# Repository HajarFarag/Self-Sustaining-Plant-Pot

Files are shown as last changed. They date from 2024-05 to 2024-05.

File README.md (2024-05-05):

# Self Sustaining Plant Pot

## Table of Contents
- [Overview](#overview)
- [Demo](#demo)
- [Features](#features)
- [Technologies Used](#technologies-used)
- [Acknowledgements](#acknowledgements)

## Overview
The purpose of the project is to leave a plant unattended so it can find optimal sunlight and water the plants when required. This is done using an Arduino to control different components to achieve the goal of the project.
<br />


## Demo
*Note: Rubber tires were used for demo since PLA tracks did not have enough friction to move properly*
### Plant pot moving towards light
<br />


### Water Reservoir
<br />


<br />

## Features
- Sunlight Detection
- Watering System
- Movement Mechanism
- Obstacle Avoidance
- Battery Powered

## Technologies Used
- [Arduino](https://www.arduino.cc/ "Arduino's Homepage") - Microcontroller platform
- [C/C++](https://cplusplus.com/ "Arduino's Homepage") - Programming language
- [Ultimaker Cura](https://ultimaker.com/software/ultimaker-cura/ "Ultimaker Cura's Homepage") - 3D printing slicing software
- [AutoDesk Inventor](https://www.autodesk.com/products/inventor/features "Autodesk Inventor's Homepage") - 3D modeling and design software

## Acknowledgements
Thanks to: 
- [Nahuel Taibo](https://www.thingiverse.com/thing:2804287/ "Nahuel Taibo STL") for the Rover Track STL

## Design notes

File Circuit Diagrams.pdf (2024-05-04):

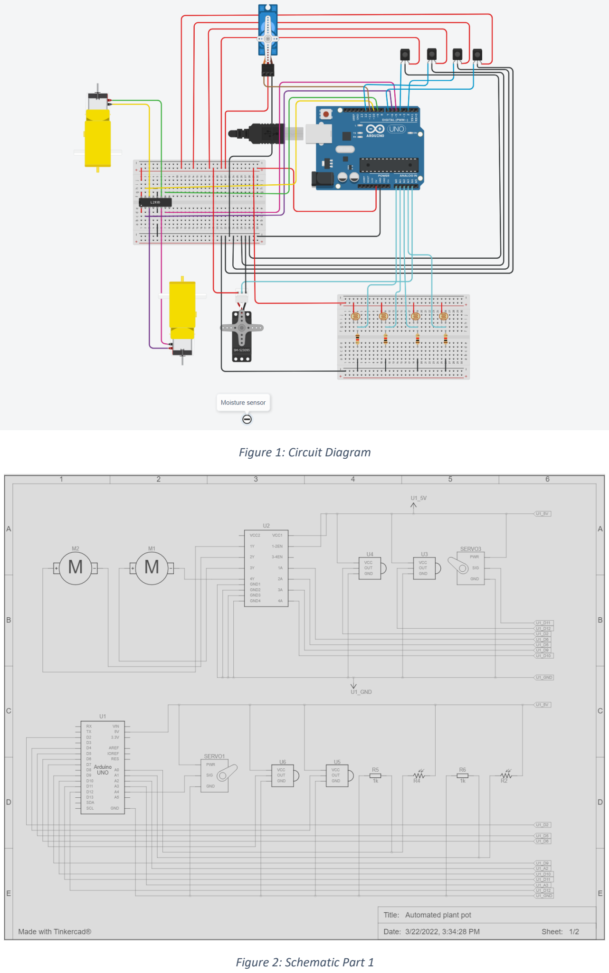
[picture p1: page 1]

Figure 1: Circuit Diagram

Figure 2: Schematic Part 1

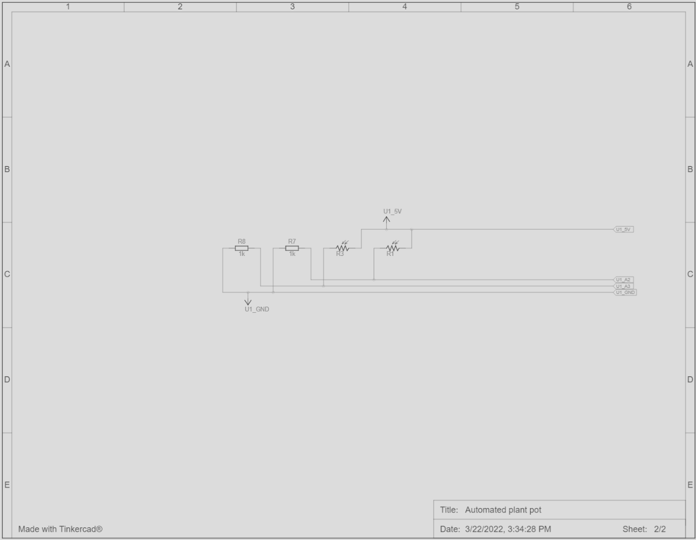
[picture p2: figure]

Figure 3: Schematic part 2

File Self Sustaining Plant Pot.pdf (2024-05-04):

Hajar Farag

Mohawk College of Applied Arts and Technology Department of Electrotechnology

## CENG-10024 – Capstone Project

Automated Plant Pot

Project submitted April 8th, 2022

Project Completed By:
Hajar Farag

2 | H a j a r F a r a g

## Abstract

This report is about the capstone project that was assigned as the final project of the program. The purpose of the project is to leave a plant unattended so it can find optimal sunlight and water the plants when required. This is done using an Arduino to control different components to achieve the goal of the project.

## Table of Contents

Abstract | 2
Table of Figures | 2

### 1. Introduction | 4 2. Theory of Operation and Background Information | 4 3. Project Description | 8 4. Bill of Materials | 8 5. Project Construction | 8 5.1. Materials needed | 8 5.2. Tools needed | 8

5.3. 3D Prints needed | 9

6. Testing and Observations | 17 6.1. Testing | 17 6.2. Observations | 17 7. Project Outcome | 18 8. Timeline and Milestones | 19 9. Conclusion | 20 10. Future Work/Recommendation | 20 11. References | 21 12. Appendix | 22 12.1 Appendix A – Code used for Automated Plant pot | 22 12.2 Appendix B – Schematic Diagram for Automated Plant Pot | 28 12.3 Appendix C – Datasheet Screenshots | 30

## Table of Figures

Figure 1: Theoretical circuitry connections | 5
Figure 2: Flow chart logic | 6
Figure 3: Sumo Bot Schematic | 7
Figure 4: Auto Watering System | 7
Figure 5: Lower section of the housing in AutoDesk Inventor | 10
Figure 6: Ultimaker Cura Orientation for Lower housing | 10

3 | H a j a r F a r a g

Figure 8: Circuitry connections (Note A Micro server was used in the diagram since a moisture sensor

4 | H a j a r F a r a g

## 1. Introduction

There are artificial lamps that could supply artificial sunlight to indoor plants, however artificial lamps do not supply the same wavelength of light as sunlight. Which would lead the plants to miss out on the full benefits of the sunlight. Nowadays everything is automated which is what gave me the idea to create an automated sunlight detecting pot. While working at Evertz, I learned how to create scripts to do automated testing. This opened my eyes to how everything around us is slowly being changed into an automated system. From smart fridges to smart cars, everything is being automated. My mother always moves her plants towards sunlight three times a day for the plants to get the optimal amount of sunlight. This system will allow the pots to move towards sunlight and waters the plants without any supervision.

## 2. Theory of Operation and Background Information

The automated plant pot will supply a sufficient amount of sunlight as well as water the plants when needed. An Arduino will be used to control the motors and collect inputs from the sensors. If the Arduino receives a value of less than 50% on the Moisture sensor, it will actuate the servo motor and move the water gate allowing water to flow to the soil. The LDR sensors send constant data to the Arduino and the Arduino checks the data in a loop. If one LDR sensor has a greater value compared to all the LDR sensors, the Arduino sends a PWM to the H-bridge which then controls the DC motors speed and direction of movement. Once the Pot starts moving, the Arduino code checks the IR sensor every loop to see if there is an object in front of the sensor. If the value on either IR sensor is above 250, the motor would move the opposite direction of the where the object is.
One of the technical issues encountered were the rover tracks. The tracks did not have enough traction since it was made from PLA filament which resulted in the pot not being able to move. One of the possible solutions would be to replace the tracks with a rubber belt which would have enough traction to move the pot. This solution was not used since the right track size was not available online.
Another solution would be replacing the tracks with rubber wheels which would make the whole pot more stable and would have enough traction to move the pot. This solution was used for demonstration since it was the optimal solution, however rubber tracks were not found tires online, so tires from Remote-Controlled Car were used instead.
Similar projects to my project would be a sumo bot: the sumo bots use motors and IR sensor which are some of the materials that the automated plant pot uses. Another similar project would be AutoPot Watering system. This is a similar application to my automated plant pot due to the watering system which waters the plants on its own. The contributions to the project would be 3D designing the housing, pot, and water reservoir, adding a moisture sensor which would detect the moisture of the plants soil, watering the plant using a water reservoir, and moving the pot towards sunlight.

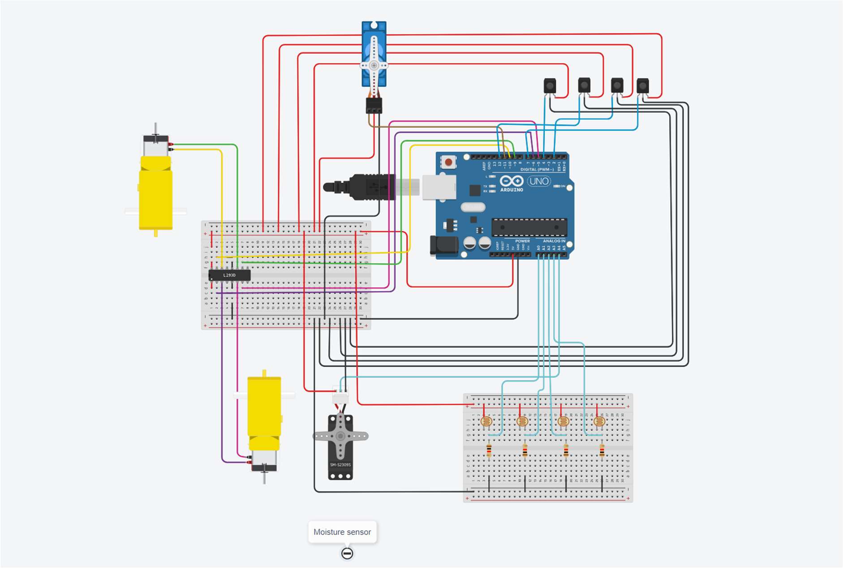
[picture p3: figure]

5 | H a j a r F a r a g

Figure 1: Theoretical circuitry connections

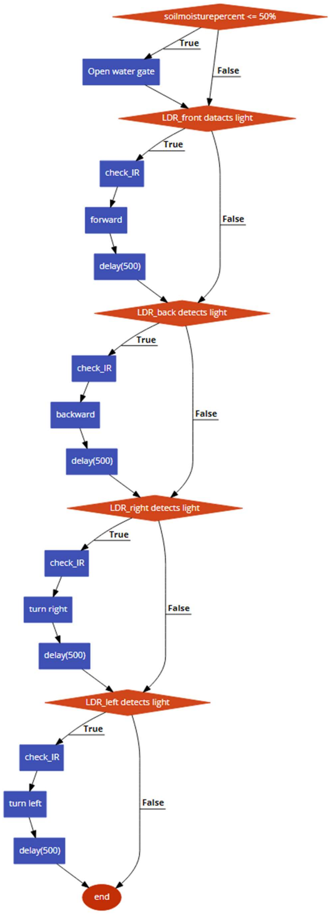
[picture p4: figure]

6 | H a j a r F a r a g

Figure 2: Flow chart logic

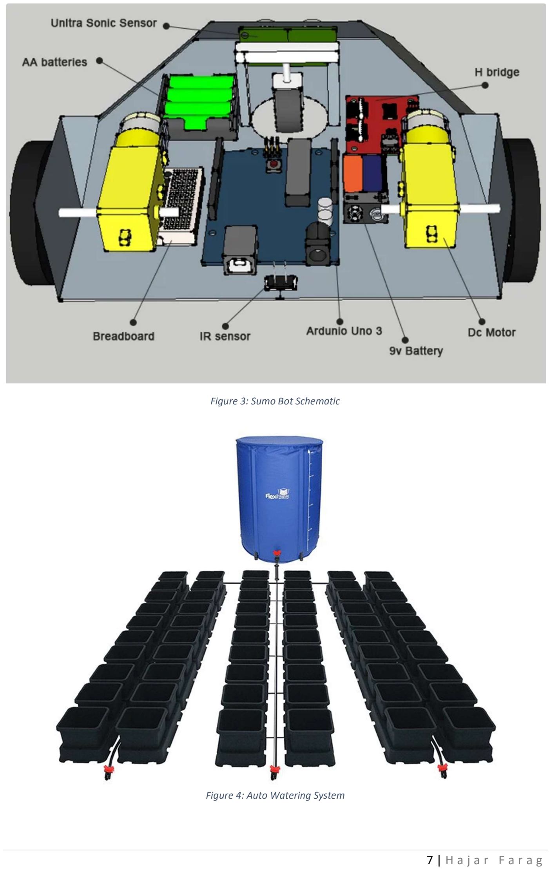
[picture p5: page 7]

7 | H a j a r F a r a g

Figure 3: Sumo Bot Schematic

Figure 4: Auto Watering System

8 | H a j a r F a r a g

## 3. Project Description

The Automated Plant Pot follows sunlight and waters the plants when the moisture of the soil decreases below a certain percentage. An Arduino based controller will be mounted on the pot which will control where the pot will move. Motors will be placed on the bottom of the pot to move the pot towards sunlight. LDR sensors will be used to detect the sunlight. IR sensors will be used to make sure the pot will not bump into anything while moving. A pulley system will be used to make the pot move to the optimal point where the sunlight is. A soil moisture sensor will be used to measure the moisture of the soil. If the moisture is low, the servo motor will rotate allowing the water to flow to the soil.

## 4. Bill of Materials

Budget Item | Quantity | Cost
DC Motor | 2 | 15
Servo Motor | 1 | 10
LDR | 4 | 10
Breadboard | 1 | 3
Capacitive Soil Moisture sensor | 1 | 10
M3x10mm Screw | 15 | 13
9V Batteries | 1 | 5
Battery House | 1 | 4.5
PLA Filament | 1 | 30
H-Bridge | 1 | 15
Total | | $115.5

## 5. Project Construction

### 5.1. Materials needed

- 1.75mm PLA Filament
- Lead Free Solder
- 1x Arduino Mega 2560
- 1x SG90 Micro Servo Motor
- 1x L298N Motor Drive
- 1x Capacitive Soil Moisture Sensor
- 1x Breadboard
- 1x Battery House (4 AA Battery Holder)
- 1x 9V Batteries
- 2x DC motors
- 4x AA Batteries
- 4x IR sensor
- 4x LDR sensors
- 4x 1k ohm resistors
- 12x M3x10mm screw
- 10x wires

### 5.2. Tools needed

- FDM Printer

9 | H a j a r F a r a g
- Screwdriver
- Soldering Iron

### 5.3. 3D Prints needed

Note: The STL files that are in a blue font are an external STL files created by a 3rd party.
- 1x Lower_Housing.stl
- 1x Upper_Housing.stl
- 1x Pot.stl
- 1x Water_Reservoir.stl
- 1x Water_Gate.stl
- 2x MotorMount_Enclosire.stl
- 2x MotorMount.stl
- 2x Wheels_Enclosure_A.stl
- 2x Wheels_Enclosure_B.stl
- 2x Wheel_Drive_A.stl
- 2x Wheel_Drive_B.stl
- 4x Wheel_Slave.stl
- 4x Wheel_Enclosure_Connector.stl
- 44x Track.stl
Procedure
The following procedure was used to create the project.
1. The STL Files listed above were printed individually.
2. A wire was attached to each pin of the DC motor using the soldering iron and solder.

### 3. The DC motor was placed in the Motor Mount Enclosure and ensured the wires were

coming out of the 10 mm opening.
4. The motor was then placed in the Motor Mount on top to secure the motor.
5. 2 wheels enclosure connectors were placed on the motor mount and motor mount enclosure to hold the parts together.
6. Wheel Drive A and Wheel Drive B were attached to the DC motor shaft by sliding them into the shaft.

### 7. A wheel slave was then placed on the motor mount enclosure and secured with a

M3x10mm screw then another wheel slave was placed on the other side of the motor mount and secured with M3x10mm screw.

### 8. Wheels Enclosure B was then aligned with the opening on the motor mount enclosure and

2 M3x10mm screws were used to attach the parts together.

### 9. The 22 Tracks were attached to each other using the 1.75 mm PLA filament and then

melting the tips to make sure the PLA does not slide off.

### 10. The tracks were then slid onto the wheel drive and wheel slave 11. Wheel Enclosure A was then placed on the Wheel Enclosure connector facing the Motor

Mount and 4 M3x10mm screws were used to attach the parts together.
12. Steps 2-11 were done again using the second DC motor.

### 13. AutoDesk Inventor was then used to design the bottom section of the housing with the

consideration of where the components will be placed.

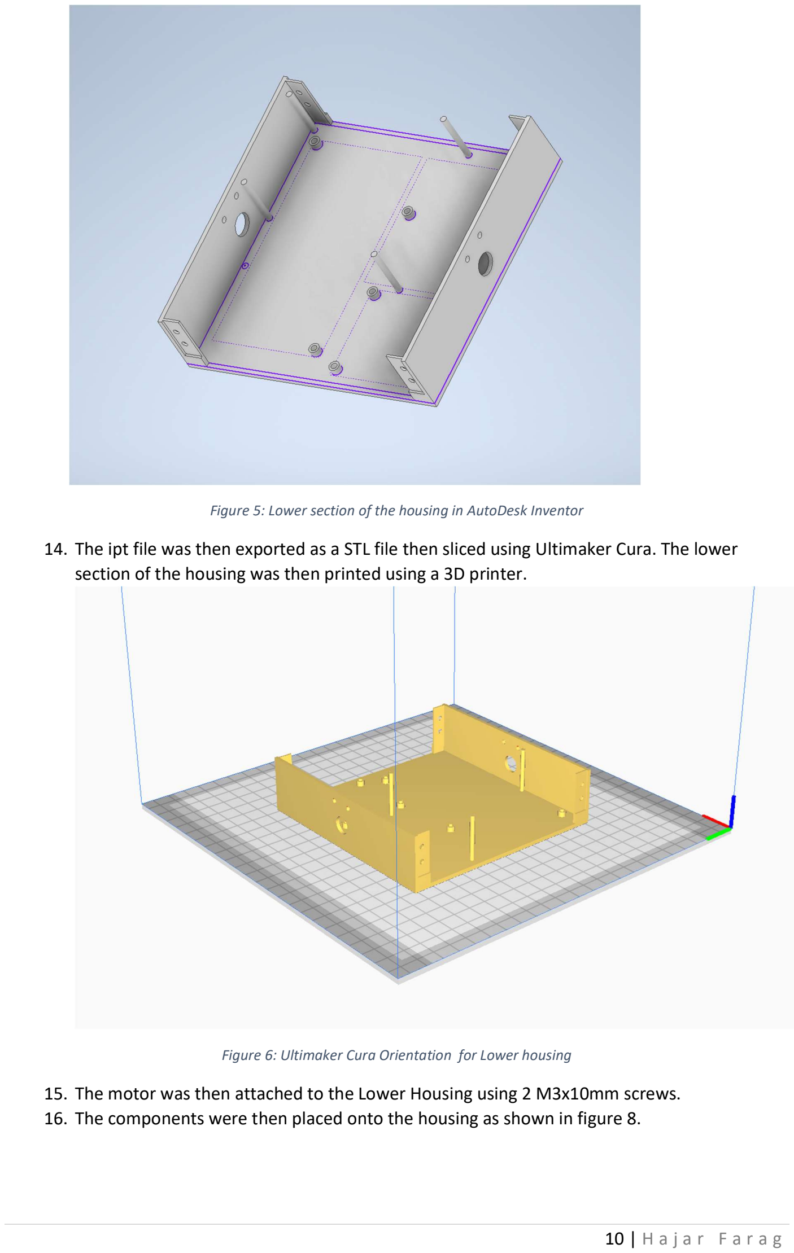
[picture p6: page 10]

10 | H a j a r F a r a g

Figure 5: Lower section of the housing in AutoDesk Inventor
14. The ipt file was then exported as a STL file then sliced using Ultimaker Cura. The lower section of the housing was then printed using a 3D printer.

Figure 6: Ultimaker Cura Orientation for Lower housing
15. The motor was then attached to the Lower Housing using 2 M3x10mm screws.
16. The components were then placed onto the housing as shown in figure 8.

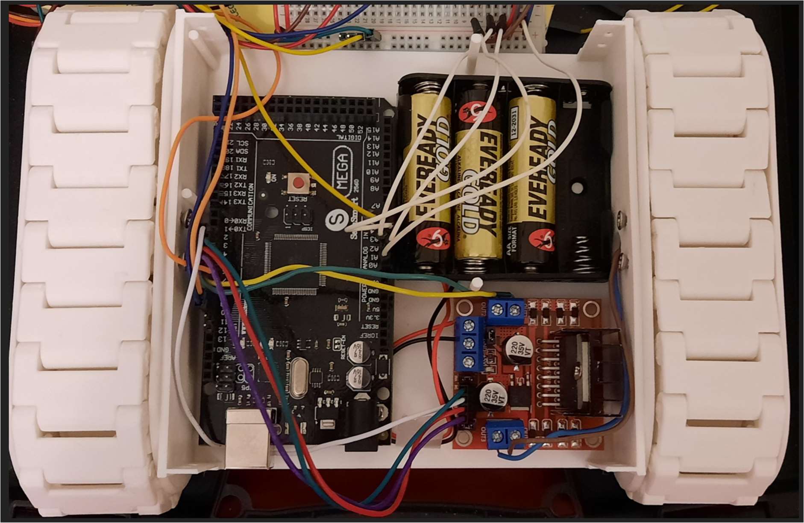
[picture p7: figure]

11 | H a j a r F a r a g

Figure 7: Components placement onto the housing
17. The circuitry was then connected using the components listed in Table 1 and was connected as shown in figure 3.

Table 1: Components needed for circuitry
2x DC Motor | 1x Servo Motor
1x H-Bridge | 1x Arduino Mega 2560
1x Moisture Sensor | 4x IR Sensor
4x 1k ohm resistor | 4x LDR Sensors

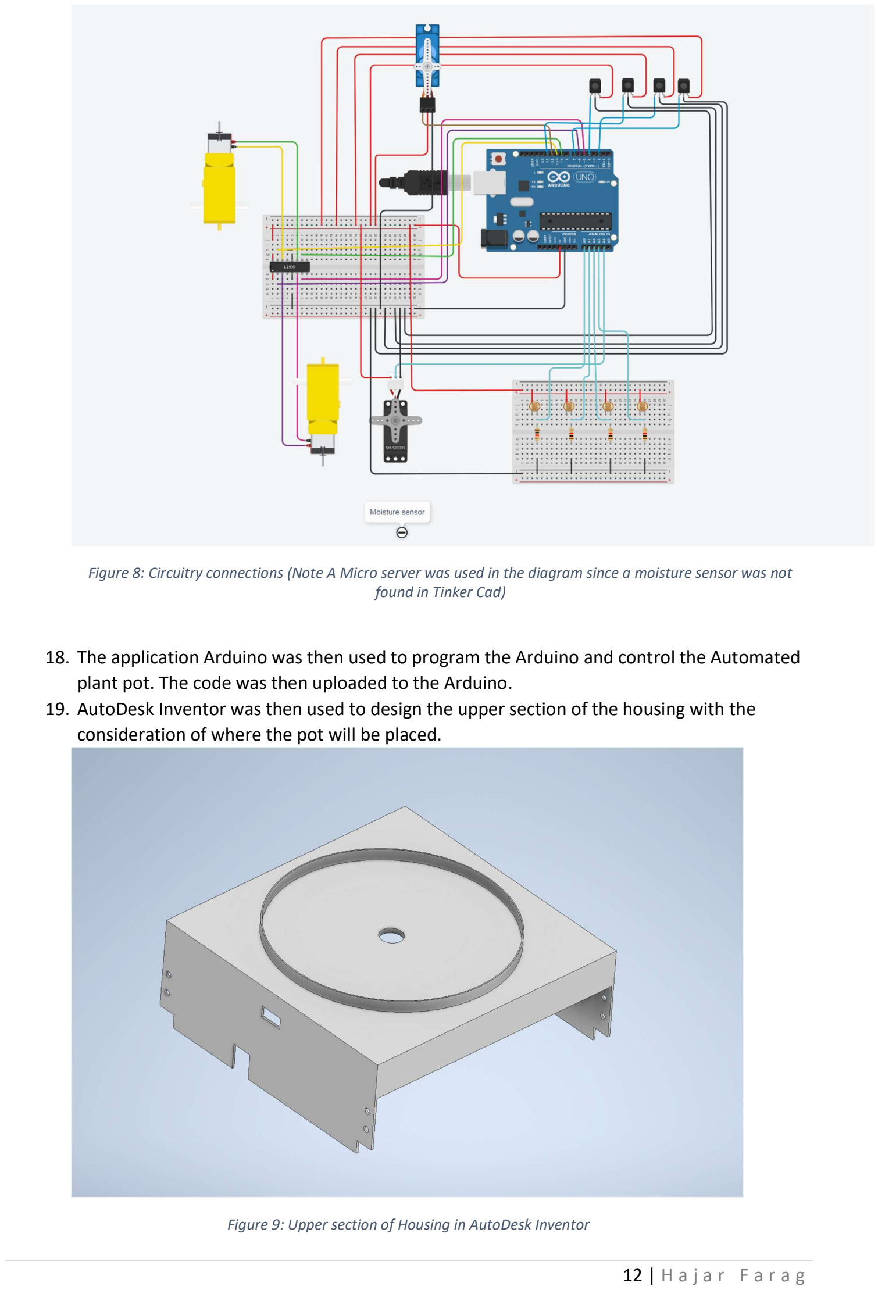
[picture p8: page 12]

12 | H a j a r F a r a g

Figure 8: Circuitry connections (Note A Micro server was used in the diagram since a moisture sensor was not found in Tinker Cad)

18. The application Arduino was then used to program the Arduino and control the Automated plant pot. The code was then uploaded to the Arduino.

### 19. AutoDesk Inventor was then used to design the upper section of the housing with the

consideration of where the pot will be placed.

Figure 9: Upper section of Housing in AutoDesk Inventor

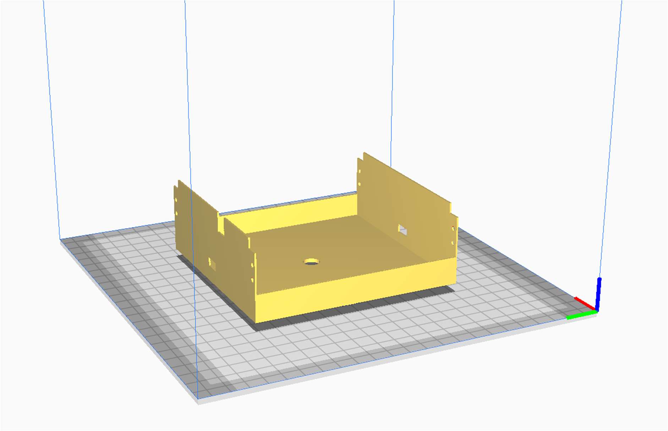
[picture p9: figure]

13 | H a j a r F a r a g
20. The ipt file was then exported as a STL file then sliced using Ultimaker Cura. The Upper section of the housing was then printed using a 3D printer.

Figure 10: Ultimaker Cura Orientation for Upper housing
21. The IR sensors, Servo Motor, and Moisture sensor were then put through the rectangular openings on the side of the upper housing.

### 22. The LDR wires were then slid into the opening ontop of the housing then 8 M3x10mm

screws were used to secure the Upper Housing to the Lower Housing.

### 23. AutoDesk Inventor was then used to design the pot with the consideration of where the

Water reservoir will be placed.

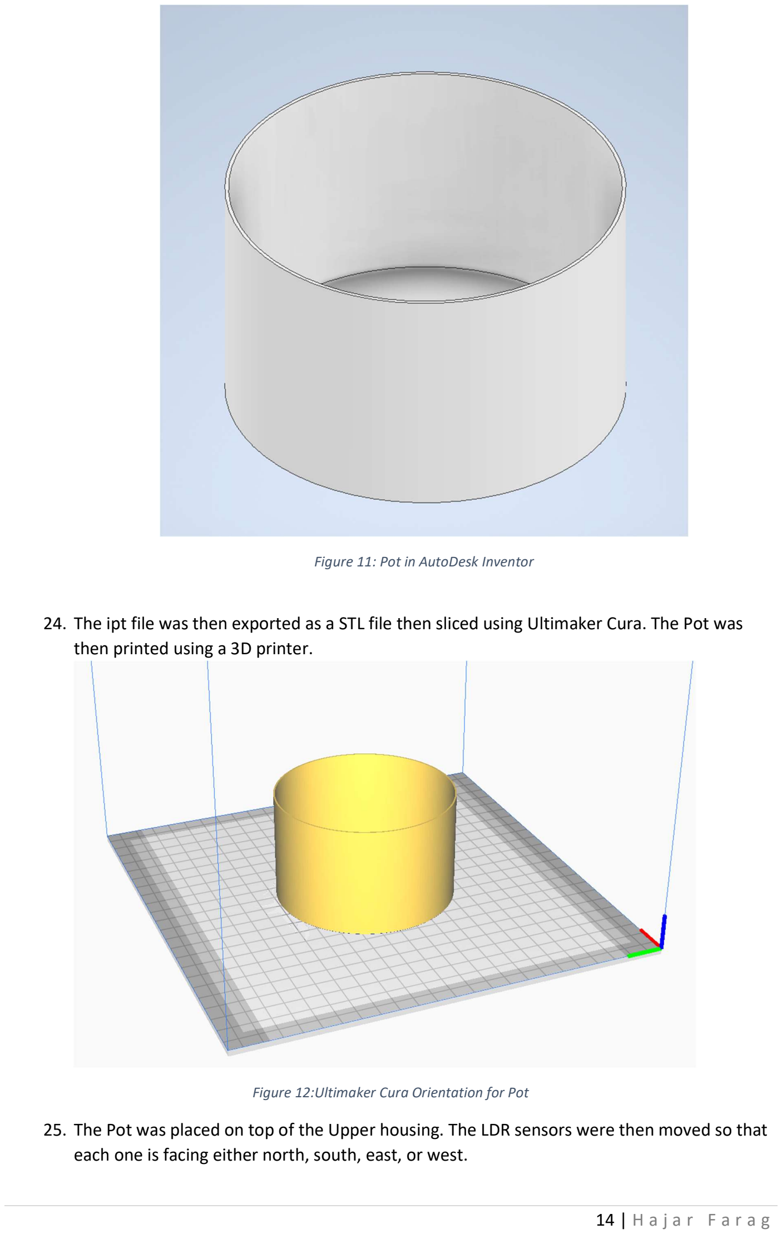
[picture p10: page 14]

14 | H a j a r F a r a g

Figure 11: Pot in AutoDesk Inventor

24. The ipt file was then exported as a STL file then sliced using Ultimaker Cura. The Pot was then printed using a 3D printer.

Figure 12:Ultimaker Cura Orientation for Pot
25. The Pot was placed on top of the Upper housing. The LDR sensors were then moved so that each one is facing either north, south, east, or west.

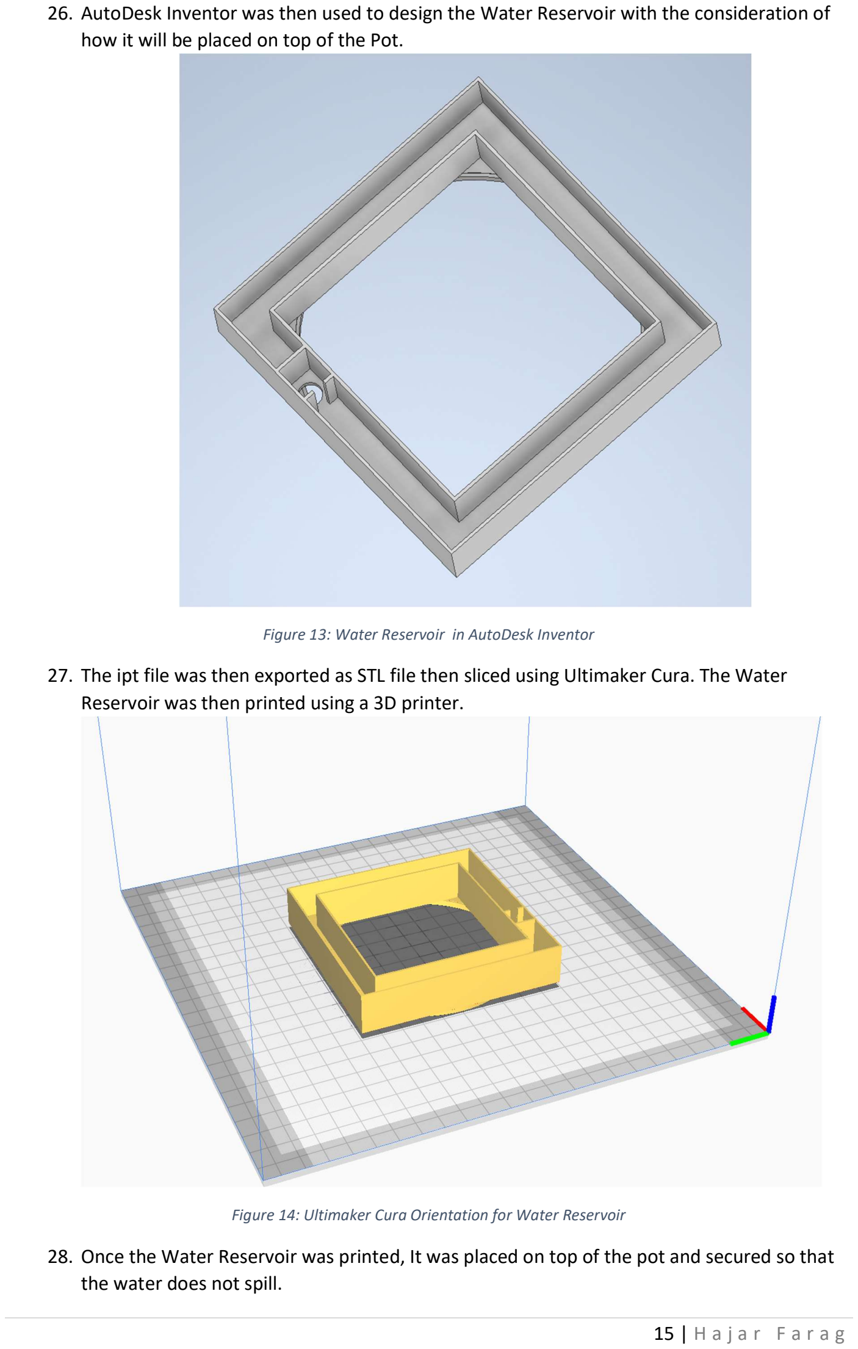
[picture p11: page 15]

15 | H a j a r F a r a g
26. AutoDesk Inventor was then used to design the Water Reservoir with the consideration of how it will be placed on top of the Pot.

Figure 13: Water Reservoir in AutoDesk Inventor
27. The ipt file was then exported as STL file then sliced using Ultimaker Cura. The Water Reservoir was then printed using a 3D printer.

Figure 14: Ultimaker Cura Orientation for Water Reservoir
28. Once the Water Reservoir was printed, It was placed on top of the pot and secured so that the water does not spill.

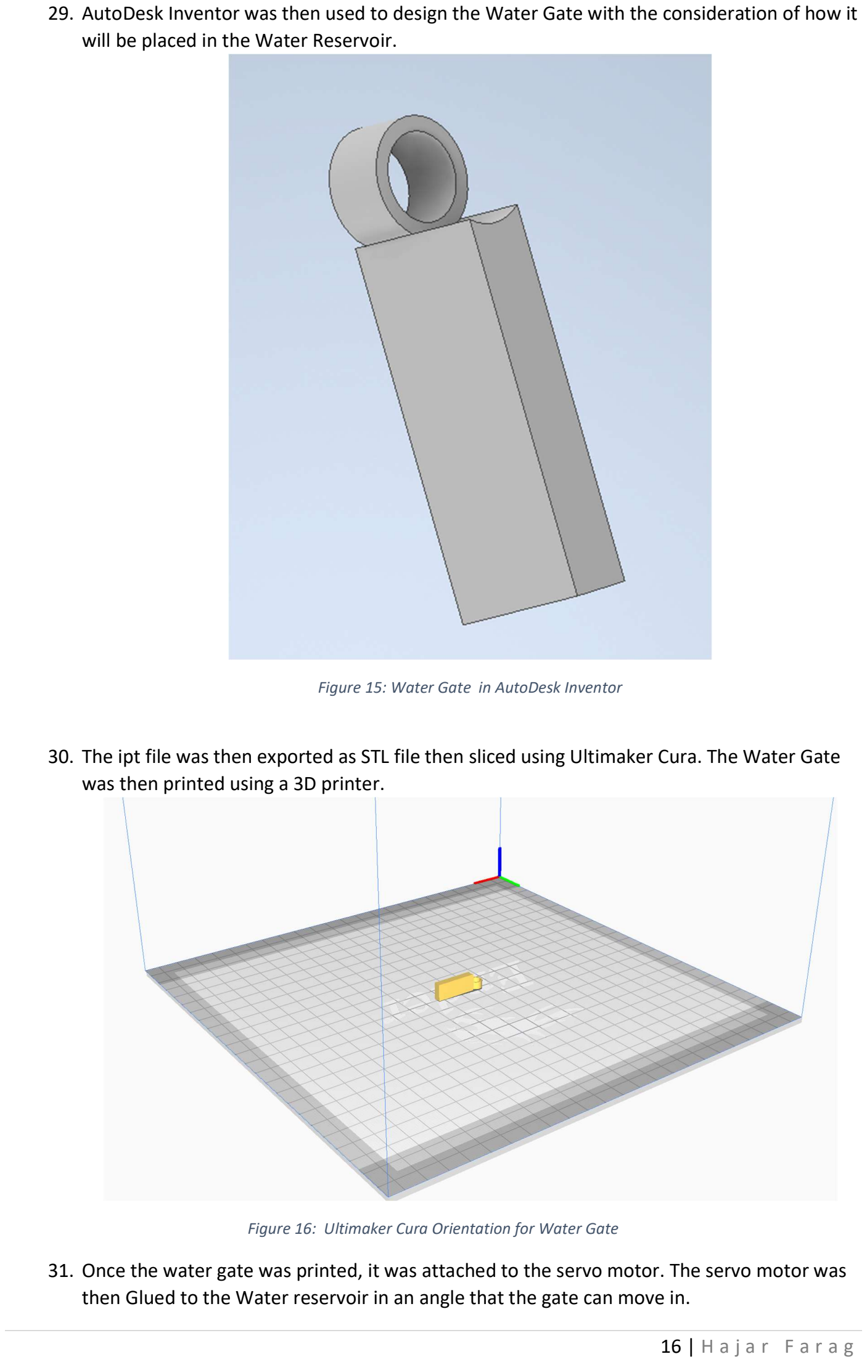
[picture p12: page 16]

16 | H a j a r F a r a g
29. AutoDesk Inventor was then used to design the Water Gate with the consideration of how it will be placed in the Water Reservoir.

Figure 15: Water Gate in AutoDesk Inventor

30. The ipt file was then exported as STL file then sliced using Ultimaker Cura. The Water Gate was then printed using a 3D printer.

Figure 16: Ultimaker Cura Orientation for Water Gate
31. Once the water gate was printed, it was attached to the servo motor. The servo motor was then Glued to the Water reservoir in an angle that the gate can move in.

17 | H a j a r F a r a g
32. The moisture sensor was then placed into the soil.

## 6. Testing and Observations

### 6.1. Testing

4 series of testing were done to ensure that the product is fully working for demonstration.
One test was the Circuitry and code testing using TinkerCAD. The Circuitry was created on TinkerCAD as well as the code. Once all the components were added to TinkerCAD and code was created, a simulation mode was then selected to test the code and ensure that the circuitry will work as needed.
Another test was done when the project was fully assembled. Once the code was uploaded, a source of light was put stationary and the pot moved towards the light as intended. This test was done for all 4 LDR’s.
Another test was done to ensure that the IR sensor is working. Once the pot started moving, an object was placed in front of one IR sensor to ensure that the pot does stops and does not keep driving towards an object.
The last test that was done was testing the water gate. The moisture sensor was placed in a dehydrated environment where the humidity was low. The humidity was decreased to ensure that the servo motor of the water gate moves so that it waters the soil.

### 6.2. Observations

The motors used for this project are DC motors used for RC cars which means that it did not have enough power to move the pot with the soil and plants on it at the expected speed. Since the weight of the Pot increased with the soil, water and plants that would require a motor with higher torque to be able to move the pot.
LDR (Light detecting resistors) sensors were used to detect sunlight, however LDR sensors detect light rather than sunlight which resulted the pot to move towards any source of light rather than sunlight.

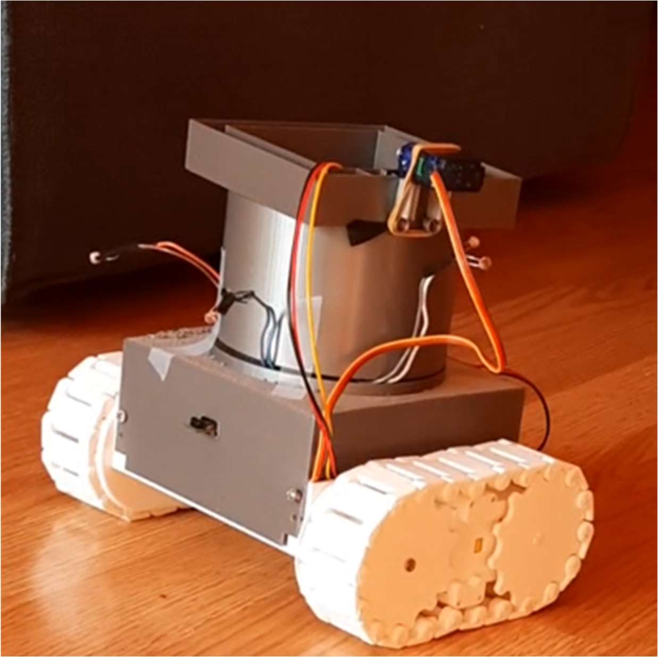
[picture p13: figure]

18 | H a j a r F a r a g

## 7. Project Outcome

Figure 17: Automated Plant Pot Fully Assembled
The capstone project was fully completed on time and demonstrated on time. The automated plant pot follows the light and waters the plant when the moisture sensor’s value decreases below 50%. The code compares all values of LDR sensors to decided which direction the robot will move in. The code also checks the IR sensor values to ensure that there are no objects in front of the Pot.

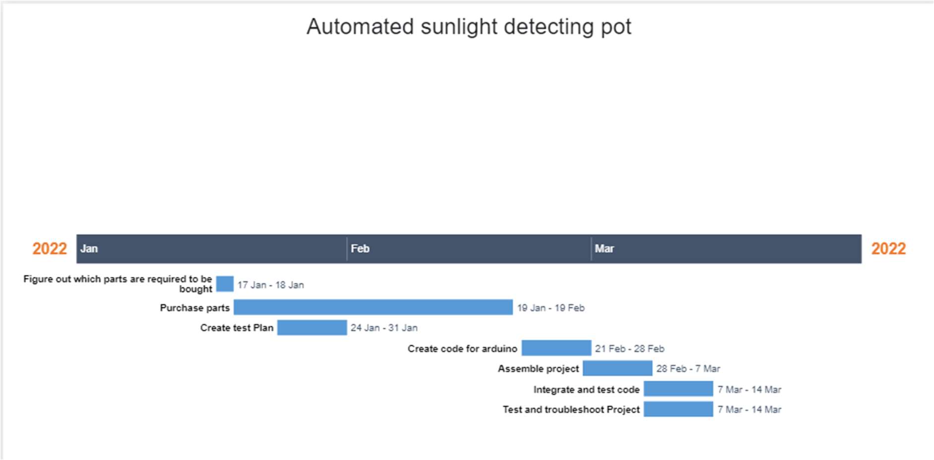
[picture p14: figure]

19 | H a j a r F a r a g

## 8. Timeline and Milestones

The making of this project went smoothly from the start. A Gantt chart was created to stay on track and help set milestones for important tasks to finish the capstone project in an orderly and time efficient manner.

Figure 18: Gantt Chart of Expected Timeline
- Proposal: Ahead of Schedule
- Purchase Items: Ahead of Schedule
- Make Schematic: Ahead of Schedule
- Circuit Assembly: Ahead of Schedule
- Arduino Script: Ahead of Schedule
- Test Script: Behind Schedule, Completed on 07/03/2022
- Design the pot: Behind Schedule, Completed on 10/03/2022
- Print the pot: On Schedule
- Assemble Project: Behind Schedule, Completed on 22/03/2022
- Test Project in real life setting: Behind Schedule, Completed on 22/03/2022
- Project Demonstration: On Schedule
- Final Report: On Schedule
The project was mostly ahead of schedule excluding a couple of milestones. Designing the pot was a bit behind schedule due to trying to optimize the pots design. Multiple prints failed or did not meet the requirements.

The key dates for accomplishing my project were

1-Planning. After figuring out what parts were needed, purchasing them was the next step. Purchasing parts was a Milestone since the right parts had to be chosen before purchasing them for the project to work

2- Coding. Creating the code is a milestone since the logic is needed to make the Automated plant pot work.

20 | H a j a r F a r a g

3- 3d Designing project was also a milestone for the capstone project. Creating a design that fit all the parts neatly while maintaining optimal operation was a major focus before moving on to the next step.

4- Assembling and testing the project was the last milestone for the capstone project. After creating a sufficient design, assembling the automated pot was the final step in the process before testing. Making sure each component fit neatly without interfering with each other before closing the component housing was key to avoid potential breakages.

## 9. Conclusion

The Automated plant pot fully functions as proposed. A flow chart was created to plan out how the logic will look like and how the automated pot will operate. Testing was made to ensure that the pot functions as proposed and all the parts work. Project management skills were used to meet the deadlines and well as plan out how the project will be constructed. Autodesk Inventor was also used to create the structure of the pot to store the components as well as function as required. Knowledge applied in this project are from courses learnt throughout the years at mohawk. The course Applied Programming helped program the Arduino to function as needed. The course Additive manufacturing helped design the housing, pot and water reservoir.

## 10. Future Work/Recommendation

Currently the pot can hold water that will last for 3 days, an improvement that can be added would be different sizes of water reservoirs to fit the needs of the user.

One other improvement that can be added would be a bigger base that can hold multiple pots. Only one pot can be placed on the current setup which is not optimal since people tend to have more than one plant in their houses. Having a bigger base would involve using stronger motors and a bigger printer bed to print parts.

Another improvement is adding idle time. Since there will be no sun after sunset the pot should stay idle and not move till sunrise. The user will be able to set the idle time since sunset and sunrise time differs depending on the season.

LDR sensors can be replaced with solar panels, which would be more optimal since Solar panels would detect sunlight rather than just light. Solar panels would also be used to set an idle time. If after 30 mins there was no sun, then Pot would go into idle mode to save the batteries.

21 | H a j a r F a r a g

## 11. References

A. Azouz, “Arduino Sumo Robot,” Instructables, 24-Apr-2019. [Online]. Available: https://www.instructables.com/How-to-Make-Arduino-Sumo-Robot/ . [Accessed: 05-Feb-2022].
B. Taibo, N., 2022. Modular Rover Tracks by nahueltaibo. [Online] Thingiverse.com. Available at: https://www.thingiverse.com/thing:2804287 [Accessed 5 February 2022].
C. “Datasheet - components101.com,” Light Detecting Resistor. [Online]. Available: https://components101.com/sites/default/files/component_datasheet/LDR%20Datashe et.pdf [Accessed: 05-Feb-2022].
D. “L298N motor driver,” L298N Dual H-Bridge Motor Driver. [Online]. Available: http://www.handsontec.com/dataspecs/L298N%20Motor%20Driver.pdf . [Accessed: 06-Feb-2022].
E. “Arduino® MEGA 2560 REV3 - docs.arduino.cc.” [Online]. Available: https://docs.arduino.cc/static/a5318e27baa5c7076e37e01d8a03072a/A000067-datasheet.pdf . [Accessed: 06-Feb-2022].

22 | H a j a r F a r a g

## 12. Appendix

### 12.1 Appendix A – Code used for Automated Plant pot

#include <Servo.h>

const int AirValue = 600;
const int WaterValue = 350; int soilmoisturepercent=0;

const int IN1=3; //Input 2 on HBridge const int IN2=4; //Input 1 on HBridge const int IN3=5; //Input 3 on HBridge const int IN4=6; //Input 4 on HBridge

const int IN5=7; //Signal on Servo Motor Servo waterGate;

const int IR_sensor_front=10; //Output of IR 1 const int IR_sensor_back=12; //Output of IR 3

#define LDR_sensor_front A0 #define LDR_sensor_left A1 #define LDR_sensor_back A2 #define LDR_sensor_right A3

#define soilMoistureValue A4

void setup(){

23 | H a j a r F a r a g

Serial.begin(9600);
waterGate.attach(IN5);
//pinMode

}

void loop(){

int moisture_value = analogRead(soilMoistureValue);

int LDR_front = analogRead(LDR_sensor_front);
int LDR_back = analogRead(LDR_sensor_back); int LDR_left = analogRead(LDR_sensor_left); int LDR_right = analogRead(LDR_sensor_right);

int IR_front = digitalRead(IR_sensor_front); int IR_back = digitalRead(IR_sensor_back);

soilmoisturepercent = map(moisture_value, AirValue, WaterValue, 0, 100);

if(soilmoisturepercent <= 50){

waterGate.write(90);
delay(1000);
waterGate.write(0);

}

if (LDR_front > LDR_back && LDR_front > LDR_left && LDR_front > LDR_right){

check_IR(255); // add function

24 | H a j a r F a r a g

delay(50);
forward(255);
delay(500);
Serial.print("FRONT");

}

else if (LDR_back > LDR_front && LDR_back > LDR_left && LDR_back > LDR_right){

check_IR(255); // add function
delay(50);
backward(255);
delay(500);
Serial.print("BACK");

}

else if (LDR_right > LDR_front && LDR_right > LDR_left && LDR_right > LDR_back){

check_IR(255); // add function
delay(50);
rotate_r(255);
delay(500);
Serial.print("RIGHT");

}

else if (LDR_left > LDR_right && LDR_left > LDR_back && LDR_left > LDR_front){

check_IR(255); // add function
delay(50);

25 | H a j a r F a r a g

rotate_l(255);
delay(500);
Serial.print("LEFT");

}

// testing code
Serial.print("LDR front: "); Serial.println(LDR_front); Serial.print("LDR_back: "); Serial.println(LDR_back);
Serial.print("LDR_left: "); Serial.println(LDR_left);
Serial.print("LDR_right: "); Serial.println(LDR_right); Serial.print("IR_front: "); Serial.println(IR_front);
Serial.print("IR_back: "); Serial.println(IR_back);
Serial.print("moisture percentage: "); Serial.println(soilmoisturepercent); }

void Stop(){
Serial.begin(9600);//When we want to Motor To stop , // just void this part on the loop section . analogWrite(IN1,0);
analogWrite(IN2,0);
analogWrite(IN3,0);
analogWrite(IN4,0);

26 | H a j a r F a r a g

}

void rotate_r (int Speed)
{
//When we want to let Motor To Rotate , // just void this part on the loop section . analogWrite(IN1,0);
analogWrite(IN2,Speed);
analogWrite(IN3,Speed);
analogWrite(IN4,0);
}

void rotate_l (int Speed)
{
//When we want to let Motor To Rotate , // just void this part on the loop section . analogWrite(IN1,Speed);
analogWrite(IN2,0);
analogWrite(IN3,0);
analogWrite(IN4,Speed);
}

void backward (int Speed){
//When we want to let Motor To move forward, // just void this part on the loop section . analogWrite(IN1,Speed);
analogWrite(IN2,0);
analogWrite(IN3,Speed);
analogWrite(IN4,0);
}

27 | H a j a r F a r a g

void forward (int Speed){
//When we want to let Motor To move forward, // just void this part on the loop section . analogWrite(IN1,0);
analogWrite(IN2,Speed);
analogWrite(IN3,0);
analogWrite(IN4,Speed);
}

void check_IR(int speed){

int IR_front = digitalRead(IR_sensor_front); int IR_back = digitalRead(IR_sensor_back);

if (IR_front == 1){

backward(speed);

}

else if(IR_back == 1){

forward(speed);

}
}

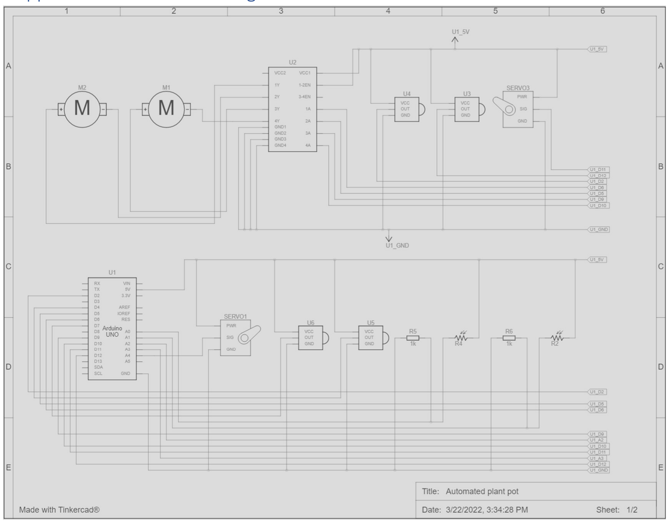
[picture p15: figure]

28 | H a j a r F a r a g

### 12.2 Appendix B – Schematic Diagram for Automated Plant Pot

Figure 19: Page 1 schematic for Automated plant pot

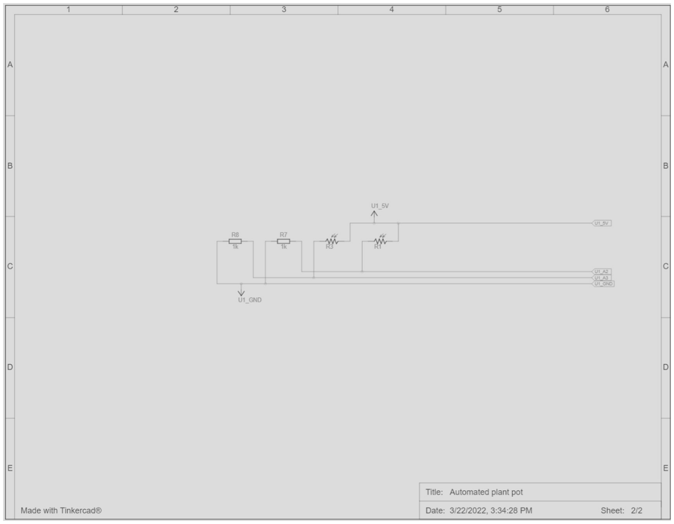
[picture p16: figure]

29 | H a j a r F a r a g

Figure 20: Page 2 schematic for Automated plant pot

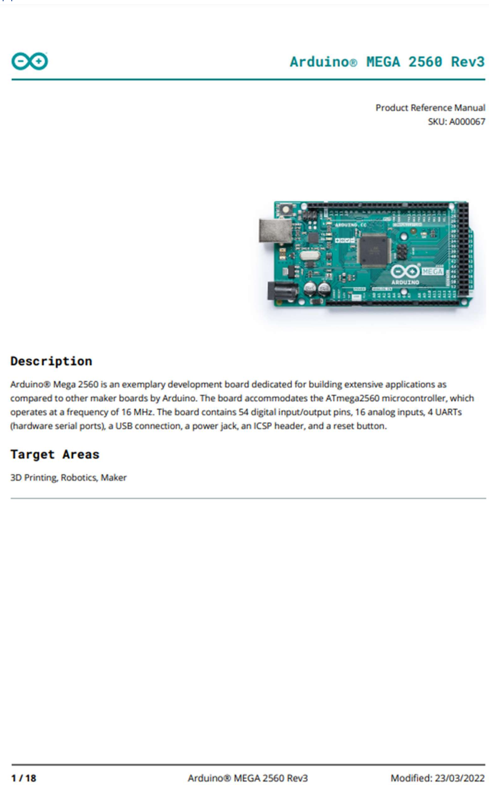
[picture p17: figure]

30 | H a j a r F a r a g

### 12.3 Appendix C – Datasheet Screenshots

Figure 21: Arduino Mega 2560 Rev3 Datasheet

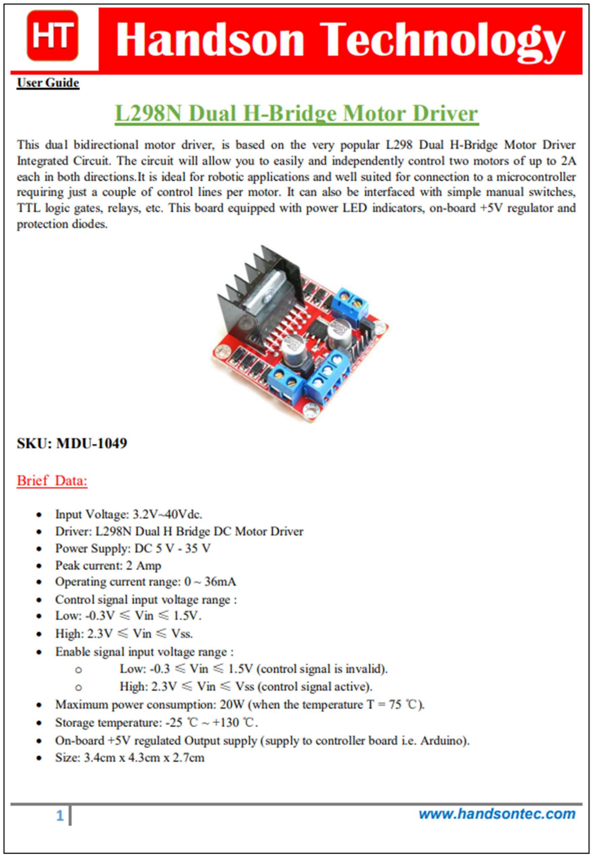
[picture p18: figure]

31 | H a j a r F a r a g

Figure 22: L298N H-Bridge Datasheet

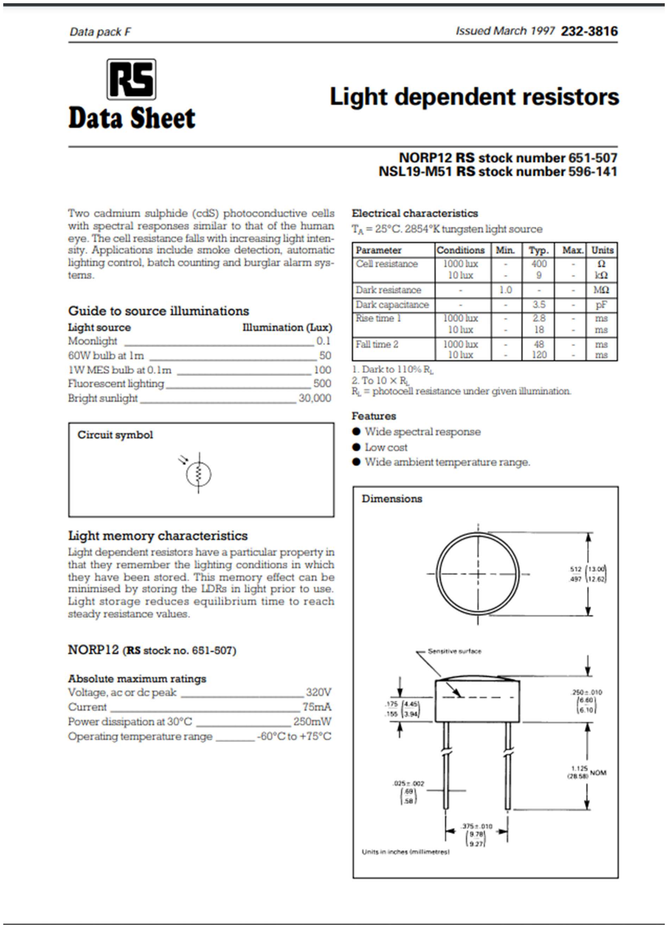
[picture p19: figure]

32 | H a j a r F a r a g

Figure 23: Light Dependant Resistor Datasheet

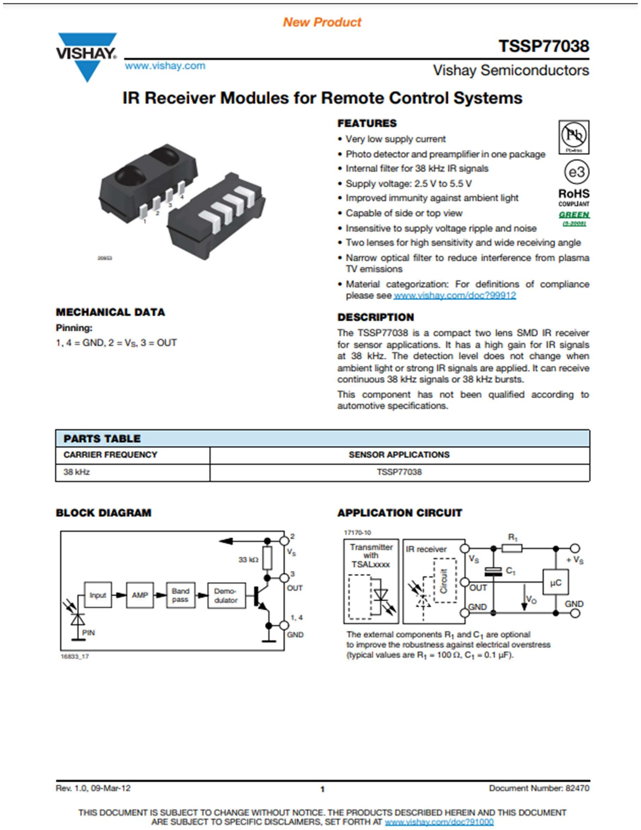
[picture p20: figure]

33 | H a j a r F a r a g

Figure 24: IR Sensor Datasheet

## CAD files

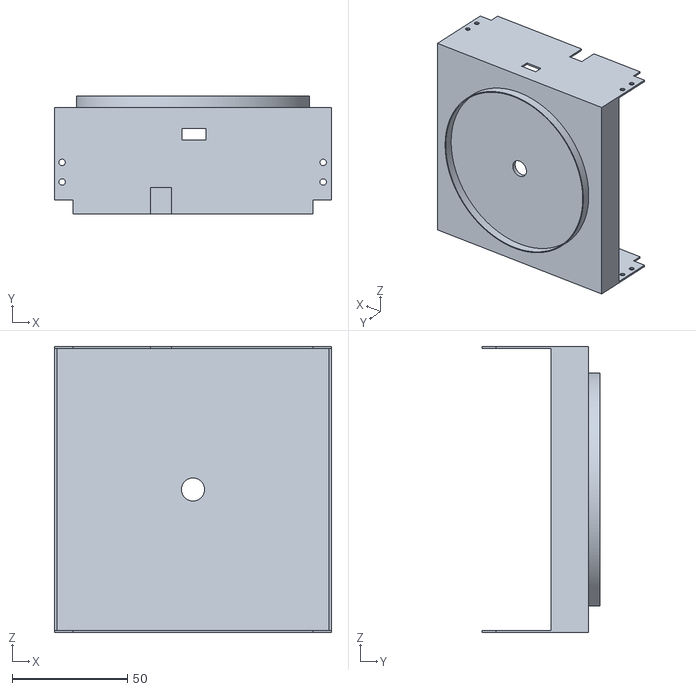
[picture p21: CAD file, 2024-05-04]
STL/Upper_Housing.stl
120.0 x 51.0 x 124.0

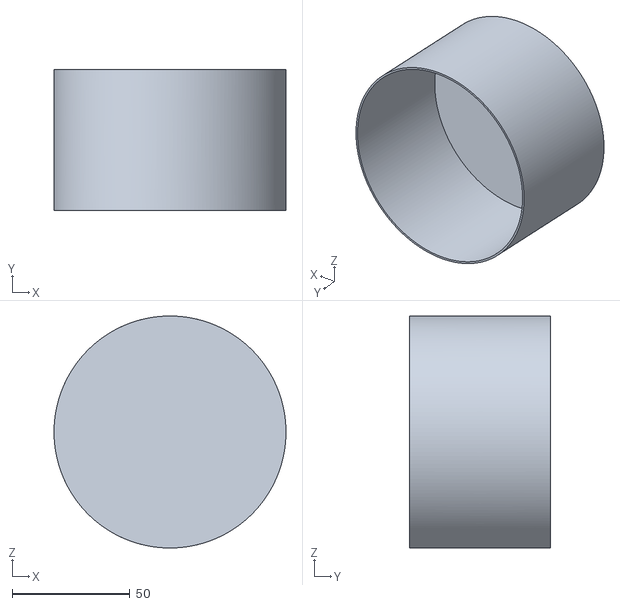
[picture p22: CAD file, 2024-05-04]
STL/pot.stl
98.6 x 60.0 x 98.6

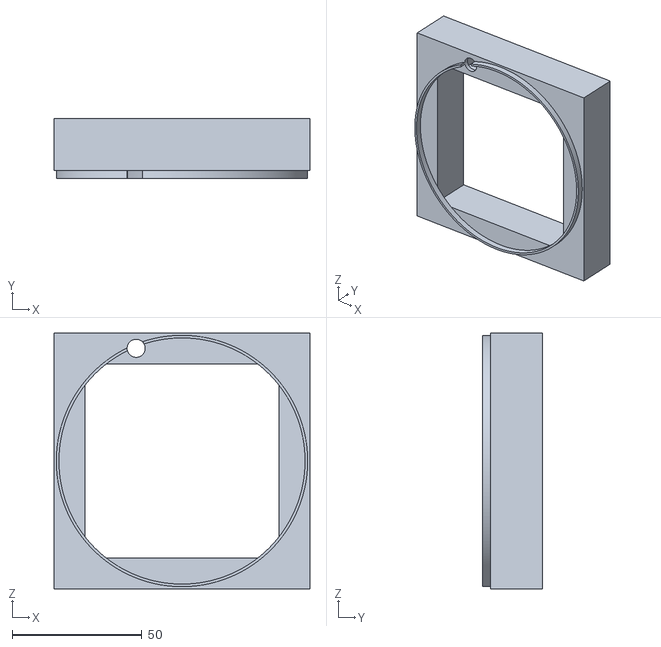
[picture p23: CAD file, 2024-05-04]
STL/water_reservoir.stl
98.6 x 23.0 x 98.6

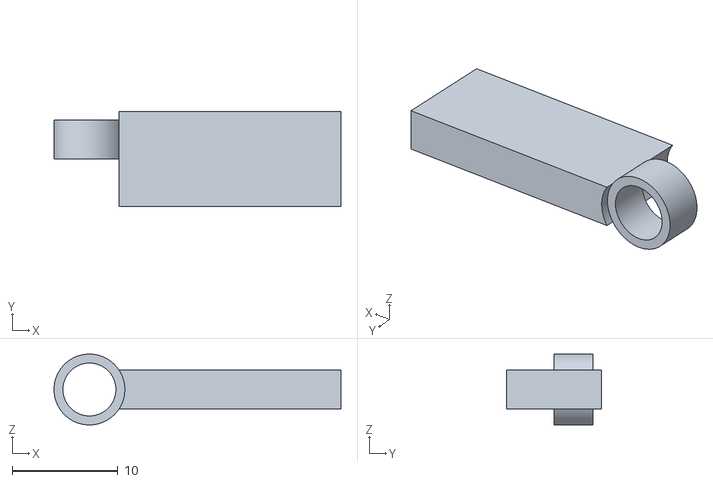
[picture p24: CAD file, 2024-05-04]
STL/water_gate.stl
27.1 x 9.00 x 6.70

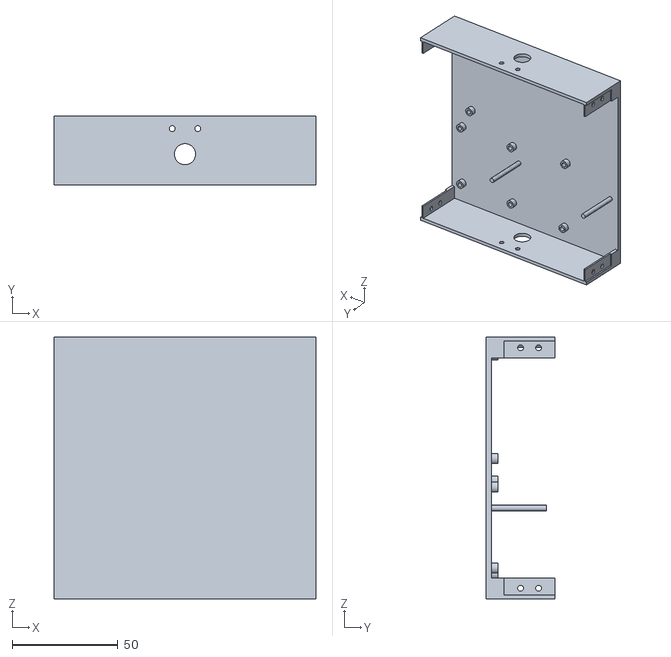
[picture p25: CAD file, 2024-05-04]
STL/Lower_Housing.stl
124.0 x 32.5 x 124.0

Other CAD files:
IPT/Lower_Housing.ipt
IPT/Upper_Housing.ipt
IPT/Water_gatee.ipt
IPT/pot.ipt
IPT/water_reservoir.ipt
